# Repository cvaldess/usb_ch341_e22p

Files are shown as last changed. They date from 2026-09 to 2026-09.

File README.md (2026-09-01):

# usb_ch341_e22p

Adaptador **USB → SPI** para usar un módulo LoRa **EBYTE E22P-868M30S** (SX1262 + PA, 30 dBm / 1 W) con **[meshtasticd](https://meshtastic.org/docs/software/linux/)** en un PC o una Raspberry Pi, sin necesidad de GPIO.

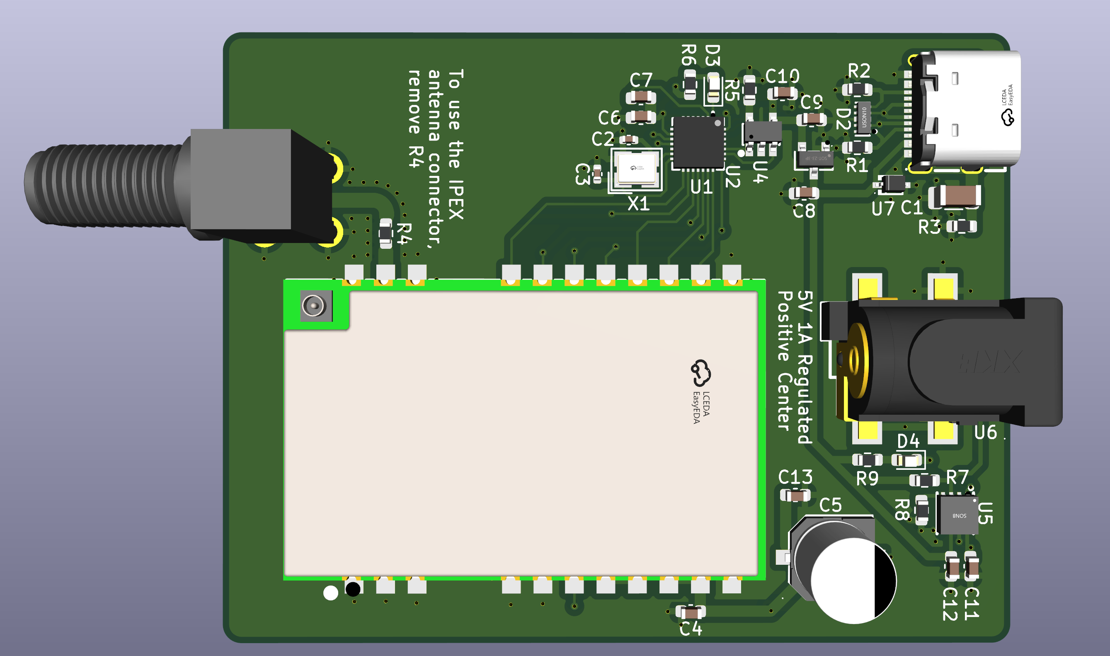
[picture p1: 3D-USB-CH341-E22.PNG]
3D-USB-CH341-E22


El puente es un **CH341F** en modo UIO, que es el que soporta el driver [`libch341-spi-userspace`](https://github.com/meshtastic/libch341-spi-userspace) de Meshtastic. Un multiplexor **TPS2115A** conmuta automáticamente entre la alimentación del USB y la de un jack DC, de modo que el módulo puede transmitir a plena potencia sin sobrecargar el puerto del ordenador.

---

## Especificaciones

| | |
|---|---|
| PCB | 49,22 × 63,54 mm · **2 capas** · 1,6 mm · vías 0,6/0,3 mm |
| Puente USB | CH341F (QFN-28), modo paralelo/síncrono (PID `0x5512`) |
| Radio | EBYTE E22P-868M30S — SX1262 + PA, hasta **30 dBm**, 868 MHz |
| Alimentación | USB-C 5 V **o** jack DC 5 V (2,5 mm), conmutación automática |
| Límite de corriente | 1,28 A nominal (TPS2115A con `R8` = 390 Ω) |
| Lógica | 3,3 V (LDO XC6206), nivel del E22P |
| Antena | SMA hembra acodada, 50 Ω |
| Configuración | EEPROM 24C02 para VID/PID/modo |

## Cómo funciona la alimentación

Es la parte menos obvia del diseño. El E22P consume **600–670 mA transmitiendo a 30 dBm**, más de lo que un puerto USB garantiza (500 mA). La placa resuelve esto con un multiplexor cuya selección es **determinista**, no por comparación de tensiones:

| USB | Jack | `D1` | `D0` | Fuente activa | LED `D4` |
|:---:|:----:|:----:|:----:|---|:---:|
| ✅ | ❌ | 0 | 0 | **USB** — usar potencia reducida | apagado |
| ✅ | ✅ | 1 | 0 | **Jack** — plena potencia | **encendido** |
| ❌ | ✅ | 0 | 0 | ninguna (Hi-Z) | — |
| ❌ | ❌ | 0 | 0 | ninguna (Hi-Z) | — |

`D0` está fijo a masa y `D1` lo gobierna el contacto de conmutación del jack, con `R7` (10 kΩ) referenciado a **VBUS**. Así `D1` codifica *«hay jack **y** hay USB»*, y de ahí salen dos propiedades útiles:

- Con el jack puesto **siempre manda el jack**, independientemente de qué fuente tenga más tensión (las dos filas útiles usan `D0`=0, donde la tabla de verdad del TPS2115A ignora la comparación `IN2>IN1`).
- **Sin USB el módulo queda sin alimentar**, que es lo que se quiere: la placa no sirve de nada desconectada del host, y así se evita que el E22P alimentado inyecte corriente por los pines del CH341 apagado.

El LED `D4` cuelga de `STAT`, que es open-drain y se pone a nivel bajo cuando `IN1` está activo: **encendido = alimentándose del jack**.

## Configuración de meshtasticd

Los pines del CH341 se numeran como líneas UIO `D0`–`D7`. El mapeo de esta placa coincide con el preset oficial `lora-usb-meshtoad-e22.yaml`:

```yaml
Lora:
  Module: sx1262
  CS: 0        # D0 · pin 15 → NSS
  RXen: 1      # D1 · pin 16 → EN   (habilitación del front-end RF)
  Reset: 2     # D2 · pin 17 → NRST
  Busy: 4      # D4 · pin 19 → BUSY
  IRQ: 6       # D6 · pin 21 → DIO1
  spidev: ch341
  DIO2_AS_RF_SWITCH: true
  DIO3_TCXO_VOLTAGE: true
  USB_VID: 0x1A86
  USB_PID: 0x5512
  # Alimentando SÓLO por USB, baja la potencia para no sobrecargar el puerto:
  # SX126X_MAX_POWER: 10
```

`SCK` va en `D3` (pin 18) y `MOSI` en `D5` (pin 20); `MISO` está en `D7` (pin 22), que junto con `D6` es entrada fija en el CH341. `DIO2_AS_RF_SWITCH` es obligatorio: en la placa el pin `DIO2` está puenteado a `T/R CTRL`, tal como indica la nota ① del manual de EBYTE.

> [!IMPORTANT]
> **La EEPROM `U2` debe estar programada** con `MODE = 0x12` para que el CH341 enumere como puerto paralelo/síncrono. Sin programar, el chip lee `SDA`/`SCL` flotantes y arranca como **puerto serie**, no como SPI. Se graba por USB con `CH341CFG` o `IMSProg`.

## Fabricación

Todo lo necesario está en [`fab/`](fab/):

| Archivo | Para qué |
|---|---|
| `gerbers-jlcpcb.zip` | Gerbers + taladros, listo para subir |
| `bom-jlcpcb.csv` | Lista de materiales |
| `cpl-jlcpcb.csv` | Posiciones para montaje |
| `*.gtp` / `*.gbp` | Capas de pasta, por si pides esténcil |

Parámetros: **2 capas, 1,6 mm, HASL o ENIG**. Nada fuera de las capacidades estándar.

### Notas sobre el BOM

- **`U3` (E22P-868M30S) y `SMA1` no tienen código LCSC**: el módulo se compra en EBYTE o en AliExpress, y el conector SMA es genérico. Ambos se sueldan aparte.
- **Los pasivos genéricos no llevan código asignado** (100 nF, 1 µF, 10 µF, y las resistencias). Son valores de stock básico y conviene dejar que el fabricante los elija de su inventario.

## Componentes principales

| Ref | Componente | Función |
|---|---|---|
| `U1` | CH341F | Puente USB ↔ SPI |
| `U2` | 24C02 | EEPROM de configuración (VID/PID/modo) |
| `U3` | E22P-868M30S | Módulo LoRa SX1262 + PA |
| `U4` | XC6206P332MR | LDO 3,3 V para el CH341 |
| `U5` | TPS2115A | Multiplexor de alimentación |
| `U6` | DC-005-2.5A | Jack DC 5 V con contacto de conmutación |
| `U7` | H7VHD3UA | TVS de protección en VBUS |
| `D2` | TPD4E05U06 | Protección ESD del USB (D+/D−/CC1/CC2) |
| `C5` | 470 µF / 16 V | Polímero sólido, 28 mΩ ESR — reserva para los picos de TX |

## Datasheets

No se incluyen los PDF en el repositorio (son material con derechos de sus fabricantes). Enlaces a las fuentes:

- [CH341 (WCH)](https://www.wch-ic.com/products/CH341.html) · [E22P-868M30S (EBYTE)](https://www.cdebyte.com/products/E22P-868M30S) · [TPS2115A (TI)](https://www.ti.com/product/TPS2115A) · [TPD4E05U06 (TI)](https://www.ti.com/product/TPD4E05U06) · [XC6206 (Torex)](https://www.torexsemi.com/products/voltage-regulators/xc6206/)
- Referencias LCSC: `C412870` (CH341F) · `C2863458` (TPS2115A) · `C138714` (TPD4E05U06) · `C20615807` (H7VHD3UA) · `C709357` (USB-C) · `C2880544` (jack) · `C9002` (cristal)

## Limitaciones conocidas

- **Sin protección en la entrada del jack.** No hay TVS ni protección de polaridad inversa en `IN1`. El E22P se daña por encima de 5,5 V y el TPS2115A tiene un máximo absoluto de 6 V: un alimentador de 9 o 12 V, o de centro negativo, destruye ambos. **Usa sólo 5 V y comprueba la polaridad.**
- **La potencia de transmisión no se detecta sola.** meshtasticd no sabe si el jack está puesto, así que `SX126X_MAX_POWER` es un ajuste fijo. Si vas a usar la placa sólo por USB, bájalo.

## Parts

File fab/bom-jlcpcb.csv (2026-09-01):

Comment | Qty | Designator | Footprint | LCSC Part # | MPN
4.7nF/1kV | 1 | C1 | Capacitor_SMD:C_1206_3216Metric | C9192
20pF | 2 | C2,C3 | Capacitor_SMD:C_0402_1005Metric | C5137579
100nF | 6 | C10,C11,C12,C4,C6,C7 | Capacitor_SMD:C_0603_1608Metric
HV1C477M0607PZ | 1 | C5 | easyeda2kicad:CAP-SMD_BD6.3-L6.6-W6.6-LS7.8-FD | C42436549 | HV1C477M0607PZ
1uF | 2 | C8,C9 | Capacitor_SMD:C_0603_1608Metric
10uF | 1 | C13 | Capacitor_SMD:C_0603_1608Metric
TPD4E05U06DQAR | 1 | D2 | easyeda2kicad:USON-10_L2.5-W1.0-P0.50-BL | C138714 | TPD4E05U06DQAR
Green | 1 | D3 | LED_SMD:LED_0603_1608Metric | C7371903
Blue | 1 | D4 | LED_SMD:LED_0603_1608Metric | C7371903
5.1K | 2 | R1,R2 | Resistor_SMD:R_0603_1608Metric
1M | 1 | R3 | Resistor_SMD:R_0603_1608Metric
0R | 1 | R4 | Resistor_SMD:R_0603_1608Metric
10K | 2 | R5,R7 | Resistor_SMD:R_0603_1608Metric
1K | 2 | R6,R9 | Resistor_SMD:R_0603_1608Metric
390R | 1 | R8 | Resistor_SMD:R_0603_1608Metric
- | 1 | SMA1 | Connectors:SMA-TH_HJ-SMA175
CH341F | 1 | U1 | easyeda2kicad:QFN-28_L4.0-W4.0-P0.40-BL-EP | C412870 | CH341F
24C02S | 1 | U2 | easyeda2kicad:SOT-23-5_L3.0-W1.6-P0.95-LS2.8-BR | C18723540 | 24C02S(XBLW)
E22P-868M30S | 1 | U3 | E22_Ebyte:PE22(900M30S) |  | E22P-868M30S
XC6206P332MR_C5148692 | 1 | U4 | easyeda2kicad:SOT-23-3_L2.9-W1.3-P1.90-LS2.4-BR | C5148692 | XC6206P332MR
TPS2115ADRBT | 1 | U5 | easyeda2kicad:SON-8_L3.0-W3.0-P0.65-TL-EP | C2863458 | TPS2115ADRBT
DC-005-2.5A-2.5-SMT | 1 | U6 | easyeda2kicad:DC-IN-TH_XKB_DC-005-2.5A-2.5-SMT | C2880544 | DC-005-2.5A-2.5-SMT
H7VHD3UA | 1 | U7 | easyeda2kicad:SOD-323_L1.7-W1.3-LS2.7-RD | C20615807 | H7VHD3UA
KH-TYPE-C-16P | 1 | USB1 | easyeda2kicad:USB-C-SMD_KH-TYPE-C-16P | C709357 | KH-TYPE-C-16P
X322512MSB4SI | 1 | X1 | easyeda2kicad:CRYSTAL-SMD_4P-L3.2-W2.5-BL | C9002 | X322512MSB4SI

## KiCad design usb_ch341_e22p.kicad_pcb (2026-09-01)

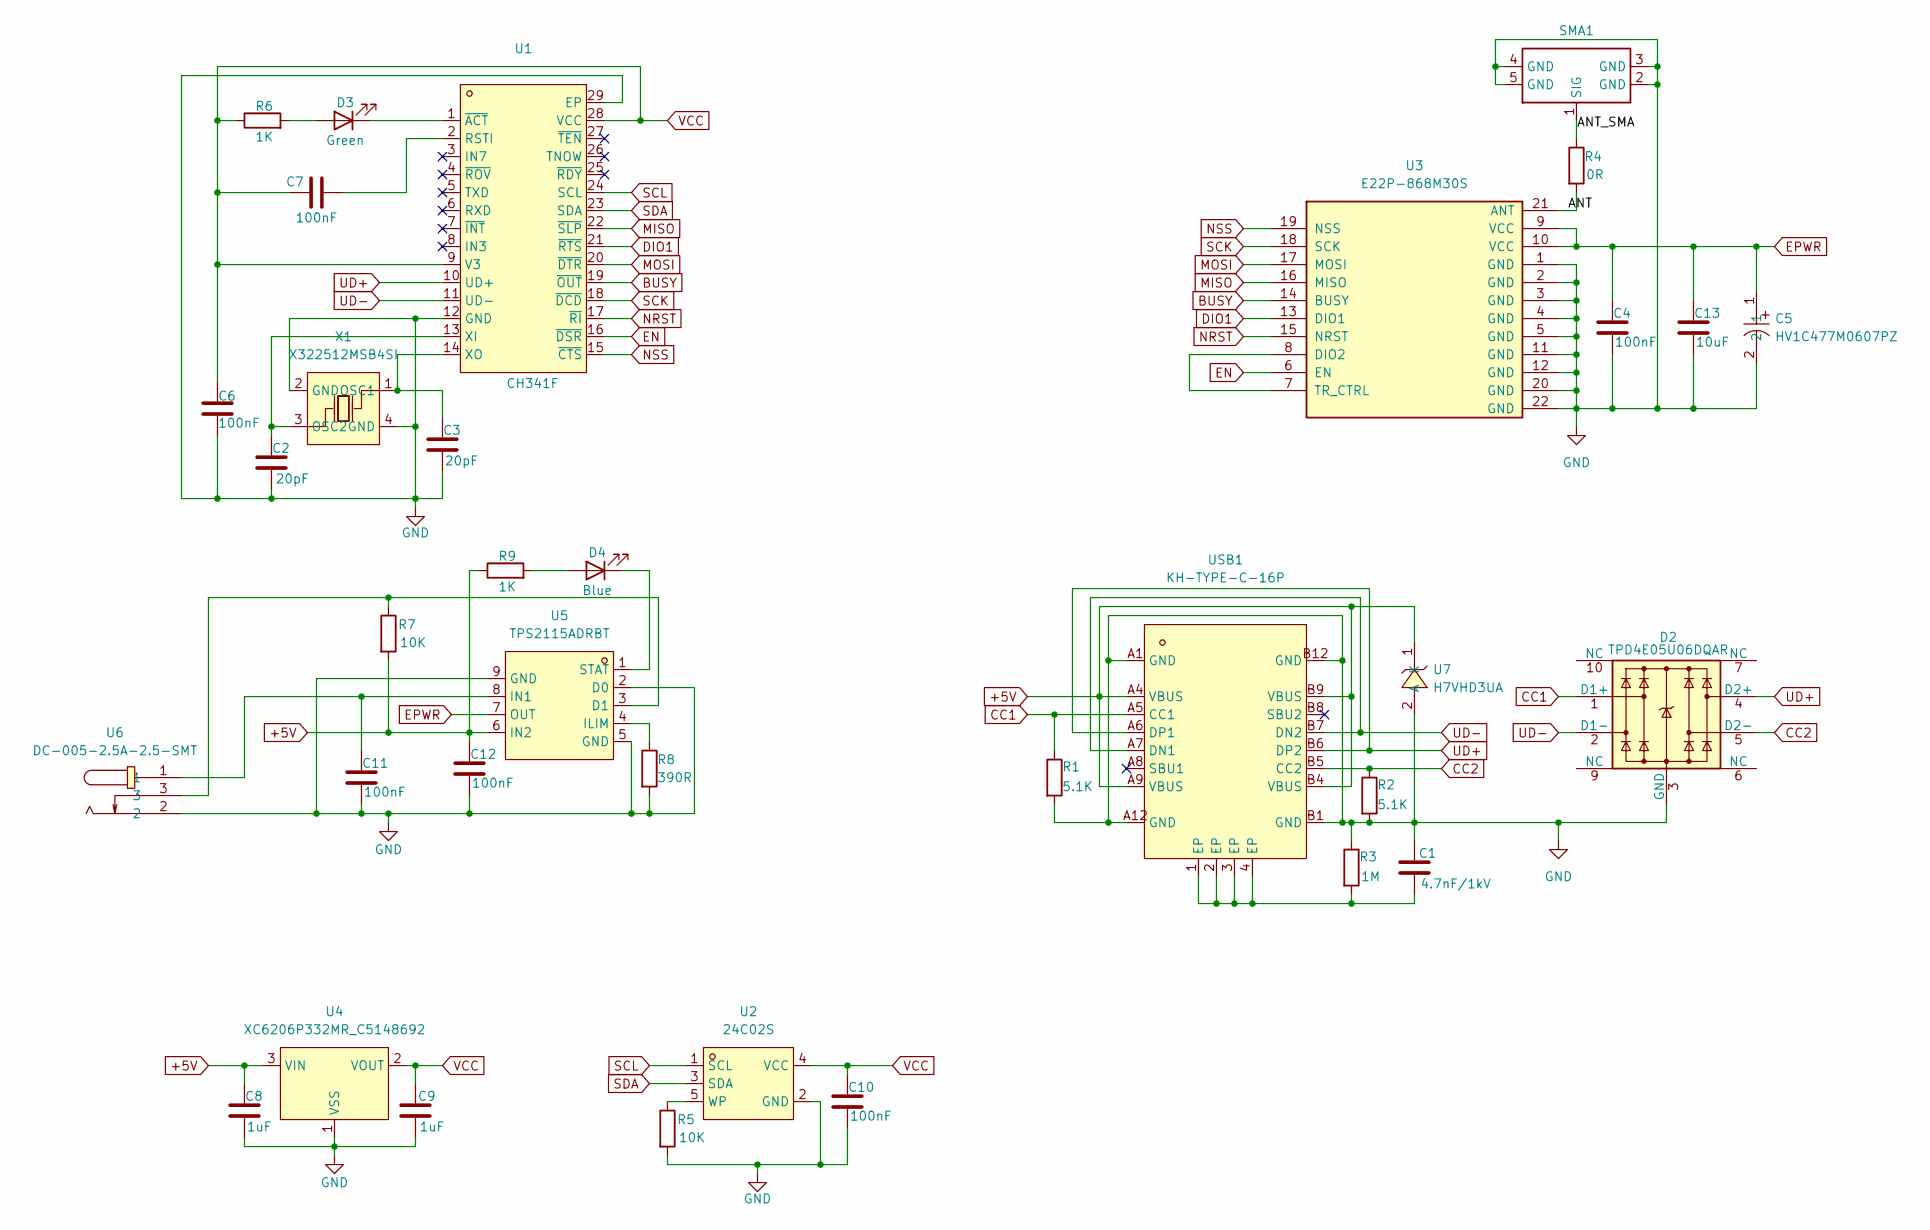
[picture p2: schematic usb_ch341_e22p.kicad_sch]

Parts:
C1: 4.7nF/1kV; C_1206_3216Metric; LCSC Part C9192
C2, C3: 20pF; C_0402_1005Metric; LCSC Part C5137579
C4, C6, C7, C10, C11, C12: 100nF; C_0603_1608Metric
C5: HV1C477M0607PZ; CAP-SMD_BD6.3-L6.6-W6.6-LS7.8-FD; MPN HV1C477M0607PZ; LCSC Part C42436549
C8, C9: 1uF; C_0603_1608Metric
C13: 10uF; C_0603_1608Metric
D2: TPD4E05U06DQAR; USON-10_L2.5-W1.0-P0.50-BL; MPN TPD4E05U06DQAR; LCSC Part C138714
D3: Green; LED_0603_1608Metric; LCSC Part C7371903
D4: Blue; LED_0603_1608Metric; LCSC Part C7371903
R1, R2: 5.1K; R_0603_1608Metric
R3: 1M; R_0603_1608Metric
R4: 0R; R_0603_1608Metric
R5, R7: 10K; R_0603_1608Metric
R6, R9: 1K; R_0603_1608Metric
R8: 390R; R_0603_1608Metric
SMA1: -; SMA-TH_HJ-SMA175; Manufacturer Part HJ-SMA175; LCSC Part Name 两件套 内孔 SMA 弯头
U1: CH341F; QFN-28_L4.0-W4.0-P0.40-BL-EP; MPN CH341F; LCSC Part C412870
U2: 24C02S; SOT-23-5_L3.0-W1.6-P0.95-LS2.8-BR; MPN 24C02S(XBLW); LCSC Part C18723540
U3: E22P-868M30S; PE22(900M30S); MPN E22P-868M30S
U4: XC6206P332MR_C5148692; SOT-23-3_L2.9-W1.3-P1.90-LS2.4-BR; MPN XC6206P332MR; LCSC Part C5148692
U5: TPS2115ADRBT; SON-8_L3.0-W3.0-P0.65-TL-EP; MPN TPS2115ADRBT; LCSC Part C2863458
U6: DC-005-2.5A-2.5-SMT; DC-IN-TH_XKB_DC-005-2.5A-2.5-SMT; MPN DC-005-2.5A-2.5-SMT; LCSC Part C2880544
U7: H7VHD3UA; SOD-323_L1.7-W1.3-LS2.7-RD; MPN H7VHD3UA; LCSC Part C20615807
USB1: KH-TYPE-C-16P; USB-C-SMD_KH-TYPE-C-16P; MPN KH-TYPE-C-16P; LCSC Part C709357
X1: X322512MSB4SI; CRYSTAL-SMD_4P-L3.2-W2.5-BL; MPN X322512MSB4SI; LCSC Part C9002

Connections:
+5V: C8.1, C12.1, R7.2, R9.1, U4.3 (VIN), U5.6 (IN2), U7.1 (K), USB1.A4 (VBUS), USB1.A9 (VBUS), USB1.B4 (VBUS), USB1.B9 (VBUS)
/ANT: R4.2, U3.21 (ANT)
/ANT_SMA: R4.1, SMA1.1 (SIG)
BUSY: U1.19 (~OUT), U3.14 (BUSY)
CC1: D2.1 (D1+), R1.1, USB1.A5 (CC1)
CC2: D2.5 (D2-), R2.1, USB1.B5 (CC2)
DIO1: U1.21 (~RTS), U3.13 (DIO1)
EN: U1.16 (~DSR), U3.6 (EN)
EPWR: C4.1, C5.1, C13.1, U3.9 (VCC), U3.10 (VCC), U5.7 (OUT)
GND: C1.1, C2.2, C3.2, C4.2, C5.2, C6.2, C8.2, C9.2, C10.2, C11.2, C12.2, C13.2, D2.3 (GND), D2.8 (GND), R1.2, R2.2, R3.1, R5.2, R8.2, SMA1.2 (GND), SMA1.3 (GND), SMA1.4 (GND), SMA1.5 (GND), U1.12 (GND), U1.29 (EP), U2.2 (GND), U3.1 (GND), U3.2 (GND), U3.3 (GND), U3.4 (GND), U3.5 (GND), U3.11 (GND), U3.12 (GND), U3.20 (GND), U3.22 (GND), U4.1 (VSS), U5.2 (D0), U5.5 (GND), U5.9 (GND), U6.2, U7.2 (A), USB1.A1 (GND), USB1.A12 (GND), USB1.B1 (GND), USB1.B12 (GND), X1.2 (GND), X1.4 (GND)
MISO: U1.22 (~SLP), U3.16 (MISO)
MOSI: U1.20 (~DTR), U3.17 (MOSI)
NRST: U1.17 (~RI), U3.15 (NRST)
NSS: U1.15 (~CTS), U3.19 (NSS)
unnamed: C1.2, R3.2, USB1.1 (EP), USB1.2 (EP), USB1.3 (EP), USB1.4 (EP)
unnamed: D3.2 (A), R6.2
unnamed: D3.1 (K), U1.1 (~ACT)
unnamed: D4.2 (A), R9.2
unnamed: D4.1 (K), U5.1 (STAT)
unnamed: C7.1, U1.2 (RSTI)
unnamed: C2.1, U1.13 (XI), X1.3 (OSC2)
unnamed: C3.1, U1.14 (XO), X1.1 (OSC1)
unnamed: R5.1, U2.5 (WP)
unnamed: U3.7 (TR_CTRL), U3.8 (DIO2)
unnamed: R7.1, U5.3 (D1), U6.3
unnamed: R8.1, U5.4 (ILIM)
unnamed: C11.1, U5.8 (IN1), U6.1
SCK: U1.18 (~DCD), U3.18 (SCK)
SCL: U1.24 (SCL), U2.1 (SCL)
SDA: U1.23 (SDA), U2.3 (SDA)
UD+: D2.4 (D2+), U1.10 (UD+), USB1.A6 (DP1), USB1.B6 (DP2)
UD-: D2.2 (D1-), U1.11 (UD-), USB1.A7 (DN1), USB1.B7 (DN2)
VCC: C6.1, C7.2, C9.1, C10.1, R6.1, U1.9 (V3), U1.28 (VCC), U2.4 (VCC), U4.2 (VOUT)

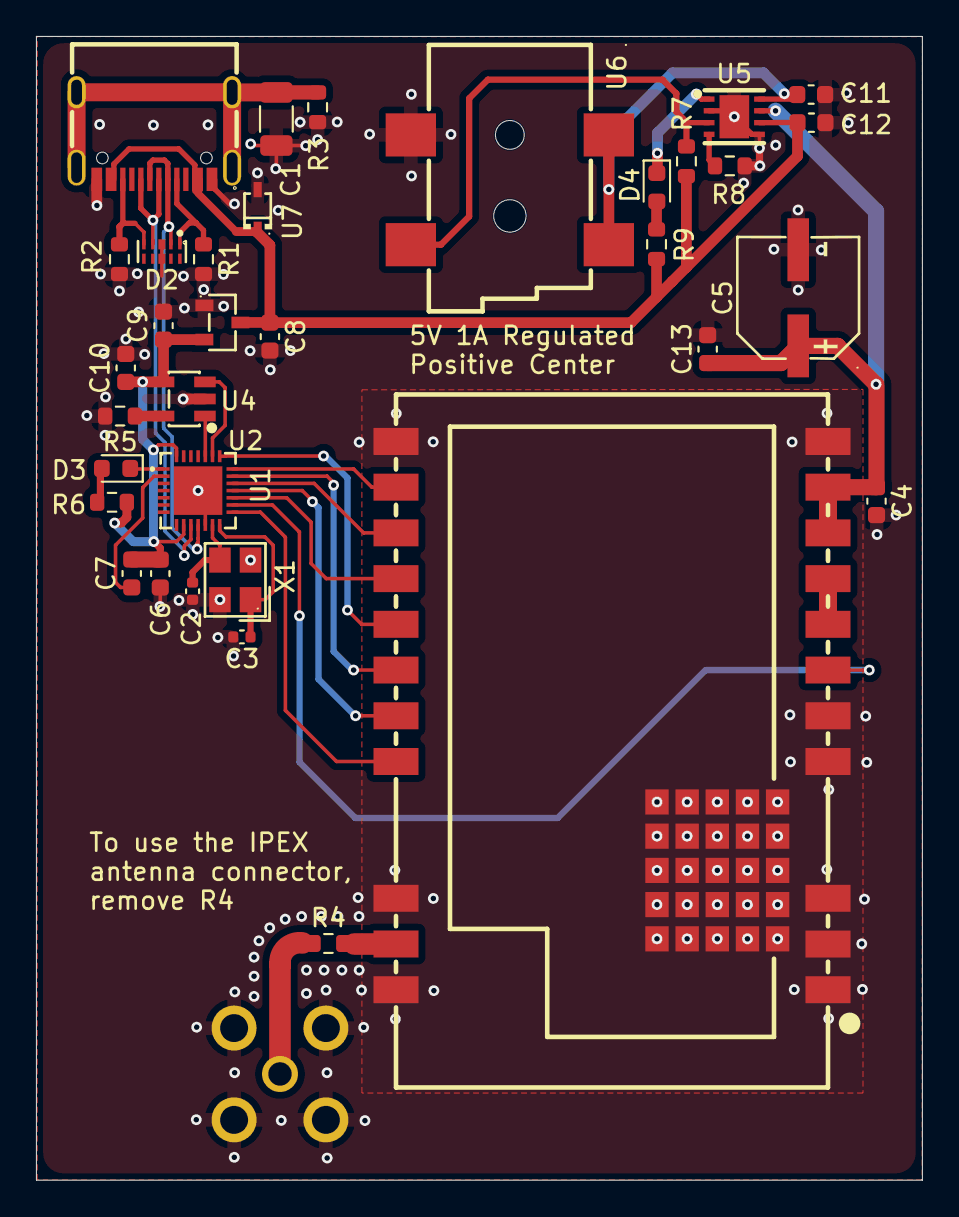
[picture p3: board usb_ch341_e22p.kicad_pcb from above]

Board: 2 copper layers, 49.2 x 63.5 mm, 35 parts (0 on the bottom side), 33 nets.

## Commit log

2026-09-01 Adaptador USB-SPI CH341F para E22P-868M30S con meshtasticd
    Placa de 2 capas (49,22 x 63,54 mm) que expone un modulo LoRa EBYTE
    E22P-868M30S por USB usando un CH341F en modo UIO, compatible con el
    driver libch341-spi-userspace de Meshtastic.
    La alimentacion la conmuta un TPS2115A de forma determinista: con el
    jack DC conectado manda el jack (plena potencia, 30 dBm), sin el jack
    manda el USB (potencia reducida), y sin USB la salida queda en alta
    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
    [bom-jlcpcb.csv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]
2026-09-01 Add 3d model
    [usb_ch341_e22p.kicad_pcb]
